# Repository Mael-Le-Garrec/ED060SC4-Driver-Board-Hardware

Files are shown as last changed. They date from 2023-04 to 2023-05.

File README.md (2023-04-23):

# ED060SC4 Driver Board

This projects intends to be a SPI driver board for the E-Ink display screen
`ED060SC4`.

This project is still under development, you can have a look at the schematics,
the PCB or the components, but it's not finished and will likely change!

## Schematics

The board is centered around 3 building blocks:

- ED060SC4, EPD screen
- STM32F103C8T6, microcontroller used to drive the screen
- TPS65185, used to generate the different rails required

The schematics can be found in [pdf](./outputs/schematics/ED060SC4_SPI_driver_board.pdf).

## Interactive Board

The PCB, nets and BOM can be seen in an [interactive html format](http://htmlpreview.github.io/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).

## Gerbers

The gerber files are available in a [zip archive](./outputs/gerbers/gerbers.zip)
ready to be sent for manufacturing.

## Images

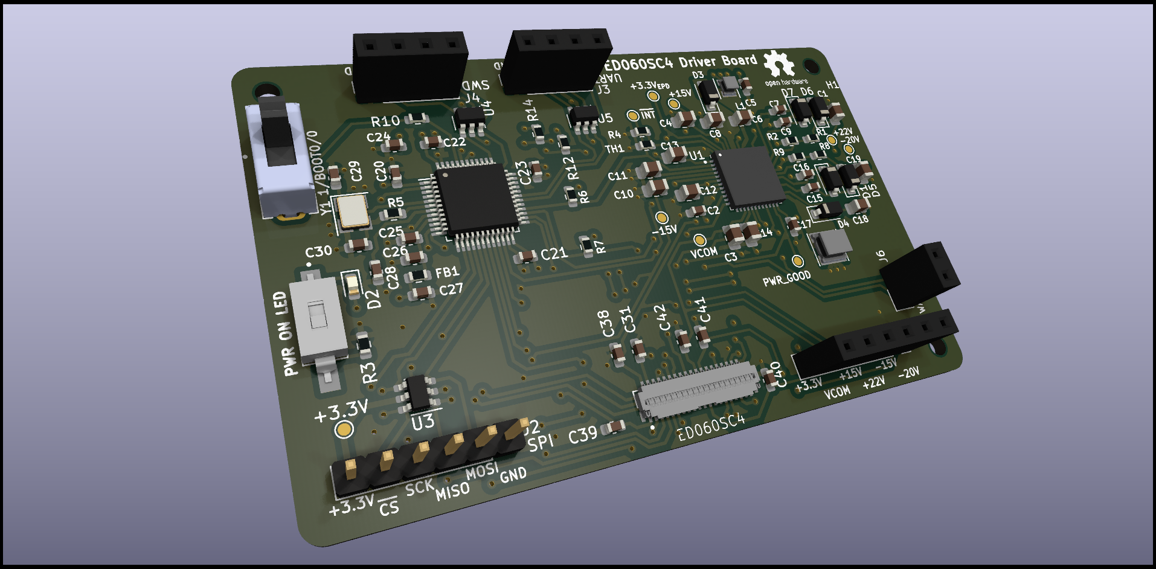
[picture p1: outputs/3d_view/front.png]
Front View

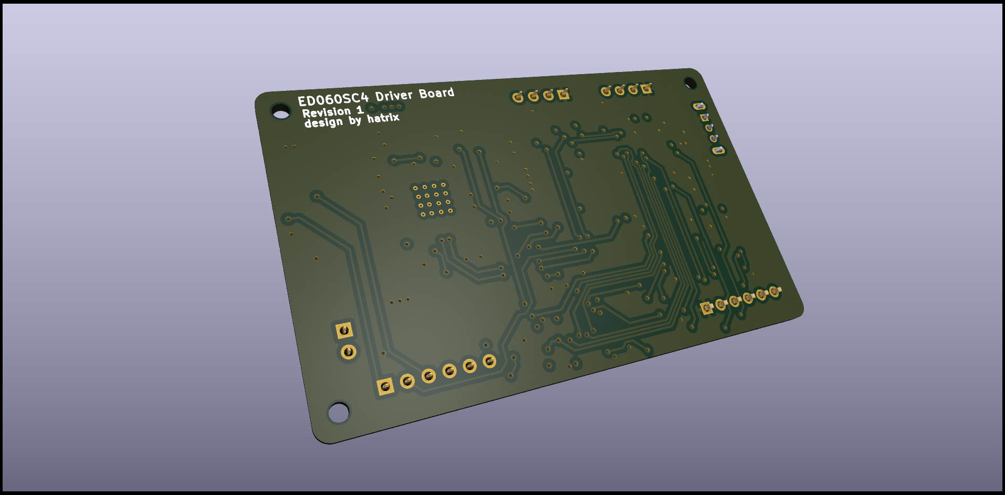
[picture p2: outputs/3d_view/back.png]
Back View

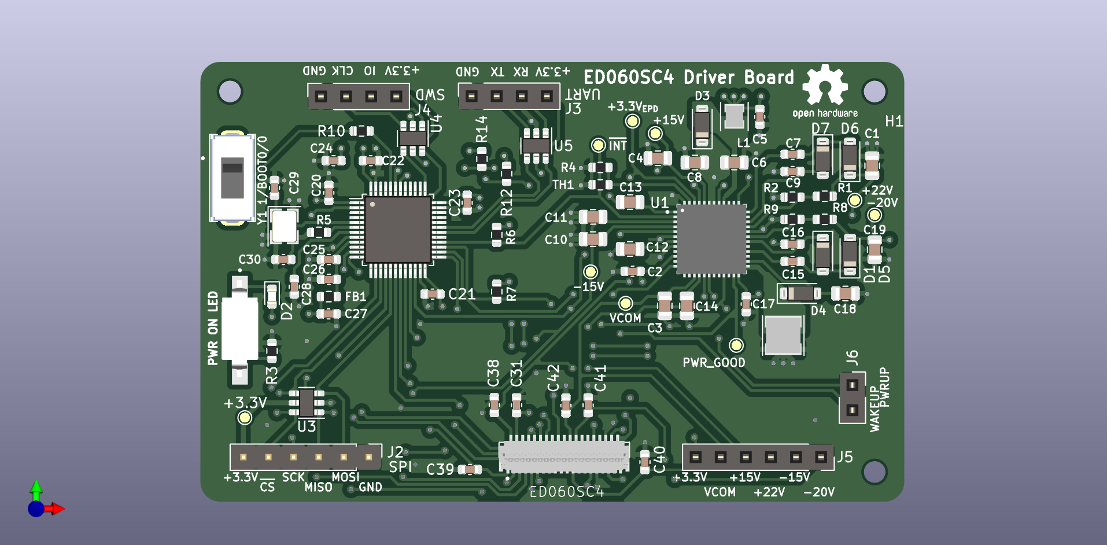
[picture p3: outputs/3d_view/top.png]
Top View

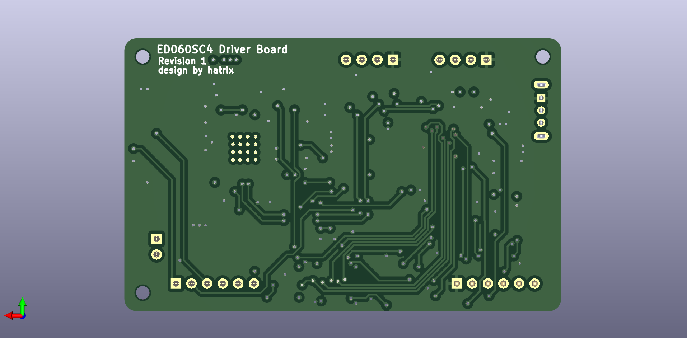
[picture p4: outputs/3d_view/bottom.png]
Bottom View


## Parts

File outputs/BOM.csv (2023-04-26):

Reference | Value | Footprint | LCSC Part # | Type | Voltage | Qty
C1, C4, C6, C8, C10, C11, C14, C18, C19 | 4.7µF | Capacitor_SMD:C_0805_2012Metric | C98192 | X6S | 50V | 9
C2, C17 | 10µF | Capacitor_SMD:C_0603_1608Metric | C85713 | X5R | 10V | 2
C3, C12, C13 | 4.7µF | Capacitor_SMD:C_0805_2012Metric | C98192 | X5R | 10V | 3
C5 | 10µF | Capacitor_SMD:C_0603_1608Metric | C85713 | X6S | 10V | 1
C7, C15 | 10nF | Capacitor_SMD:C_0603_1608Metric | C1589 | X7R | 25V | 2
C9, C16 | 100nF | Capacitor_SMD:C_0603_1608Metric | C1591 | X7R | 25V | 2
C20-C23, C28, C31, C42 | 100nF | Capacitor_SMD:C_0603_1608Metric | C1591 |  |  | 7
C24 | 10µF | Capacitor_SMD:C_0603_1608Metric | C85713 |  |  | 1
C25 | 10nF | Capacitor_SMD:C_0603_1608Metric | C1589 |  |  | 1
C26, C27 | 1µF | Capacitor_SMD:C_0603_1608Metric | C5673 |  |  | 2
C29, C30 | 10pF | Capacitor_SMD:C_0603_1608Metric | C1634 |  |  | 2
C38-C41 | 100nF | Capacitor_SMD:C_0603_1608Metric | C1591 |  | 50V | 4
D1, D5-D7 | D | Diode_SMD:D_SOD-123 | C82544 |  |  | 4
D2 | RED | LED_SMD:LED_0603_1608Metric | C82544 |  |  | 1
D3, D4 | D_Schottky | Diode_SMD:D_SOD-123 | C82544 |  |  | 2
FB1 | 120Ω@100MHz | Resistor_SMD:R_0603_1608Metric | C14709 |  |  | 1
H1, H2, H4 | M3 hole | MountingHole:MountingHole_2.2mm_M2 |  |  |  | 3
J1 | ED060SC4 | local_lib:HRS_FH26W-39S-0.3SHW(60) | C92280 |  |  | 1
J2 | Conn_01x06 | Connector_PinHeader_2.54mm:PinHeader_1x06_P2.54mm_Vertical |  |  |  | 1
J3, J4 | Conn_01x04 | Connector_PinSocket_2.54mm:PinSocket_1x04_P2.54mm_Vertical |  |  |  | 2
J5 | Conn_01x06 | Connector_PinSocket_2.54mm:PinSocket_1x06_P2.54mm_Vertical |  |  |  | 1
J6 | Conn_01x02 | Connector_PinSocket_2.54mm:PinSocket_1x02_P2.54mm_Vertical |  |  |  | 1
L1 | 2.2µH | local_lib:TDK_VLS252015ET-2R2M | C136232 |  |  | 1
L2 | 4.7µH | Inductor_SMD:L_Taiyo-Yuden_NR-40xx | C92936 |  |  | 1
R1, R8 | 1M | Resistor_SMD:R_0603_1608Metric | C105578 |  |  | 2
R2 | 47.5k | Resistor_SMD:R_0603_1608Metric | C137715 |  |  | 1
R3 | 1k | Resistor_SMD:R_0603_1608Metric | C22548 |  |  | 1
R4 | 43k | Resistor_SMD:R_0603_1608Metric | C137719 |  |  | 1
R5 | 0 | Resistor_SMD:R_0603_1608Metric | C103196 |  |  | 1
R6, R7, R10, R12, R14 | 10k | Resistor_SMD:R_0603_1608Metric | C98220 |  |  | 5
R9 | 52.3k | Resistor_SMD:R_0603_1608Metric | C185323 |  |  | 1
SW1 | SS12D07VG2 | local_lib:SW_SS12D07VG4 | C2939724 |  |  | 1
SW2 | DSIC01LSGET | local_lib:DSIC01LSGET | C54948 |  |  | 1
TH1 | 10k NTC | Resistor_SMD:R_0603_1608Metric | C13564 |  |  | 1
TP1-TP9 | TestPoint | TestPoint:TestPoint_Pad_D1.0mm |  |  |  | 9
U1 | TPS65185RGZR | local_lib:QFN50P700X700X100-49N | C139291 |  |  | 1
U2 | STM32F103C8T6 | Package_QFP:LQFP-48_7x7mm_P0.5mm | C8734 |  |  | 1
U3 | USBLC6-4SC6 | Package_TO_SOT_SMD:SOT-23-6 | C5197386 |  |  | 1
U4, U5 | USBLC6-2SC6 | Package_TO_SOT_SMD:SOT-23-6 | C2827654 |  |  | 2
Y1 | 16MHz, 10pF | Crystal:Crystal_SMD_3225-4Pin_3.2x2.5mm | C112972 |  |  | 1

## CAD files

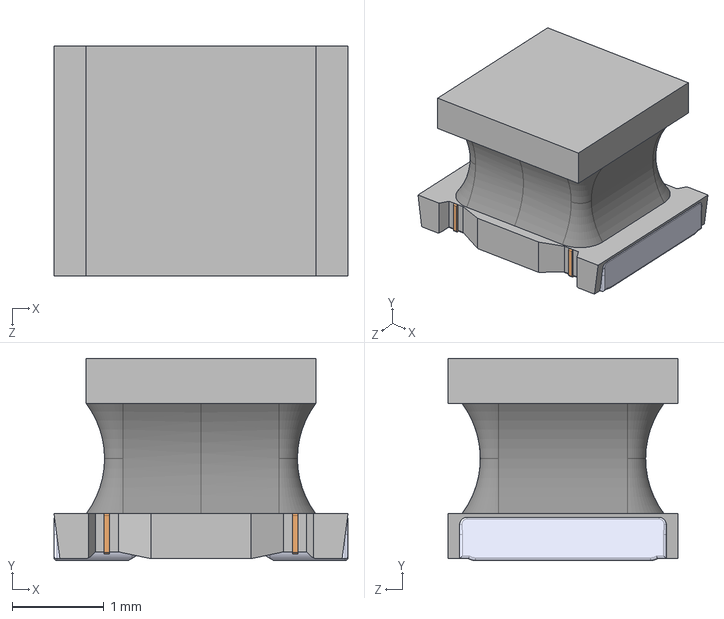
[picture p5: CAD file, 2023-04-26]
3d_models/generic_inductance.STEP
3.20 x 2.20 x 2.50 mm

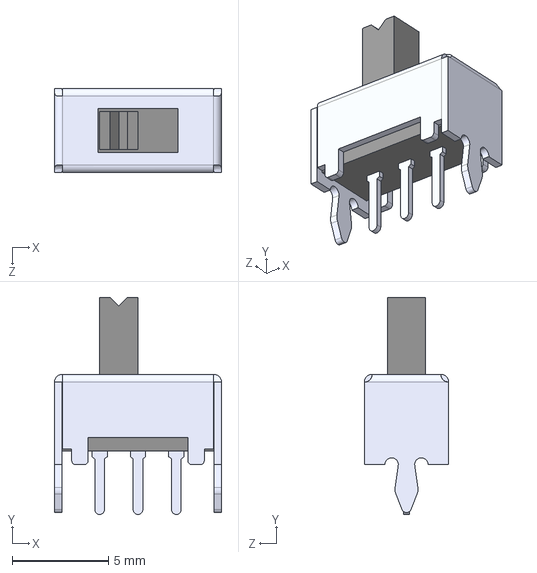
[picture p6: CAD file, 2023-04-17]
3d_models/SS12D07VG4.step
8.70 x 11.3 x 4.40 mm

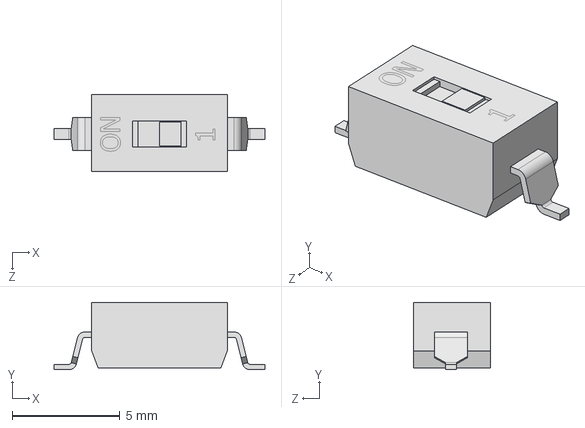
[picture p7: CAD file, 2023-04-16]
3d_models/KAE01SGGT.step
9.80 x 3.13 x 3.58 mm

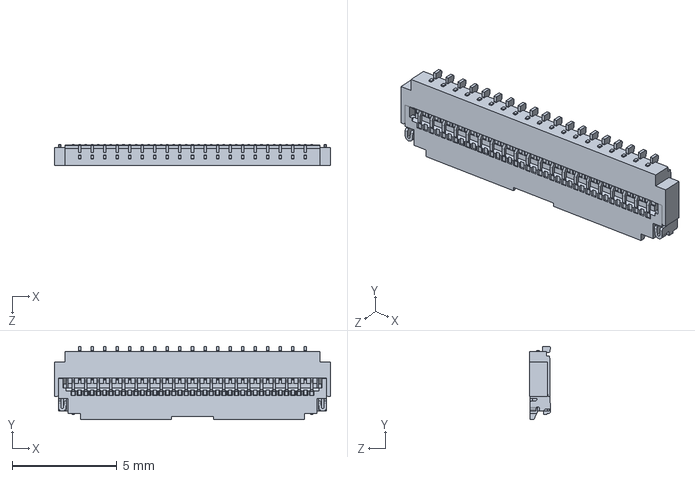
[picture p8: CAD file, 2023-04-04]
3d_models/WFH-2000118.STEP
13.2 x 3.50 x 1.00 mm

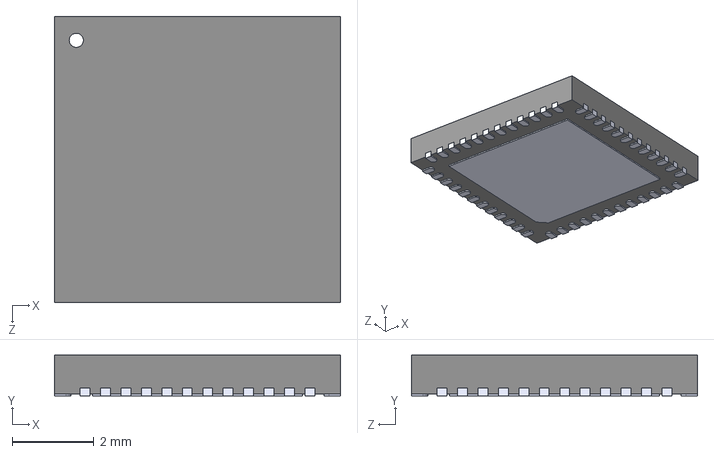
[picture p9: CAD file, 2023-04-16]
3d_models/TPS65185RGZR.step
7.00 x 1.00 x 7.00 mm

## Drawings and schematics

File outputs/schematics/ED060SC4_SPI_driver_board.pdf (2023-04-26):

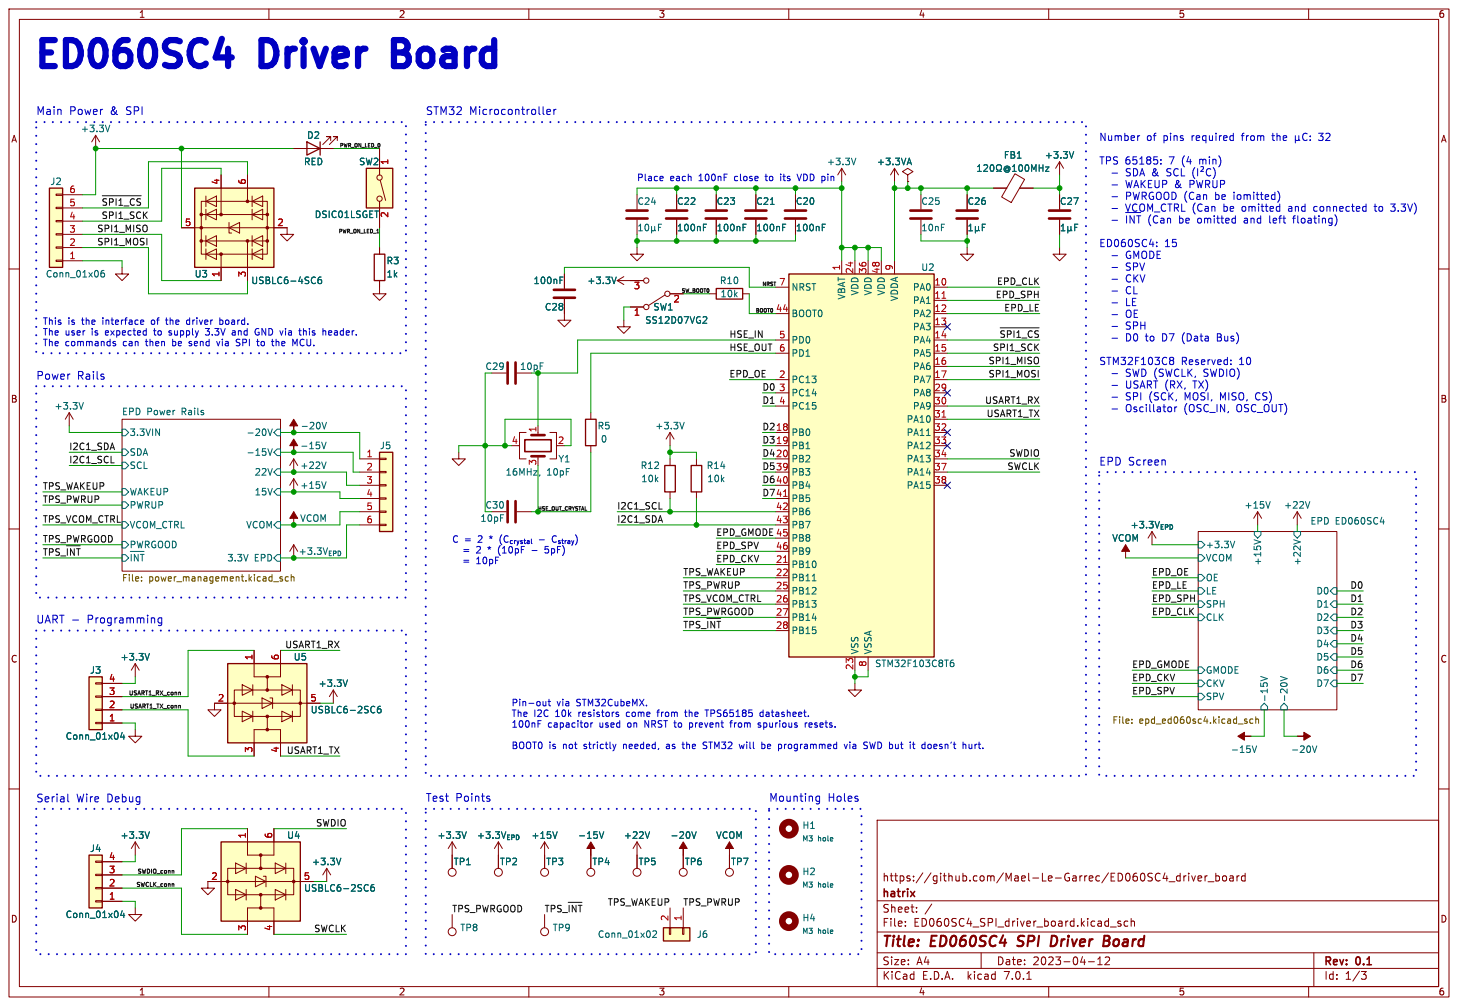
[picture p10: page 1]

- SDA & SCL þÿ(I²C)
- WAKEUP & PWRUP
- PWRGOOD (Can be iomitted)
- ~{INT}(Can be omitted and left floating) ED060SC4: 15

1 PA0 10 PA1 11 PA2 12 PA3 13 PA4 14 PA5 15 PA6 16 PA7 17 PB0 18 PB1 19 PC13 2 PB2 20 PB10 21 PB11 22 VSS 23 VDD 24 PB12 25 PB13 26 PB14 27 PB15 28 PA8 29 PC14 3 PA9 30 PA10 31 PA11 32 PA12 33 PA13 34 VDD 36 PA14 37 PA15 38 PB3 39 PC15 4 PB4 40 PB5 41 PB6 42 PB7 43 BOOT0 44 PB8 45 PB9 46 VDD 48 PD0 5 PD1 6 NRST 7 VSSA

- SWD (SWCLK, SWDIO)
- USART (RX, TX)
- SPI (SCK, MOSI, MISO, CS)

https://github.com/Mael-Le-Garrec/ED060SC4_driver_board

Id: 1/3 Title: ED060SC4 SPI Driver Board

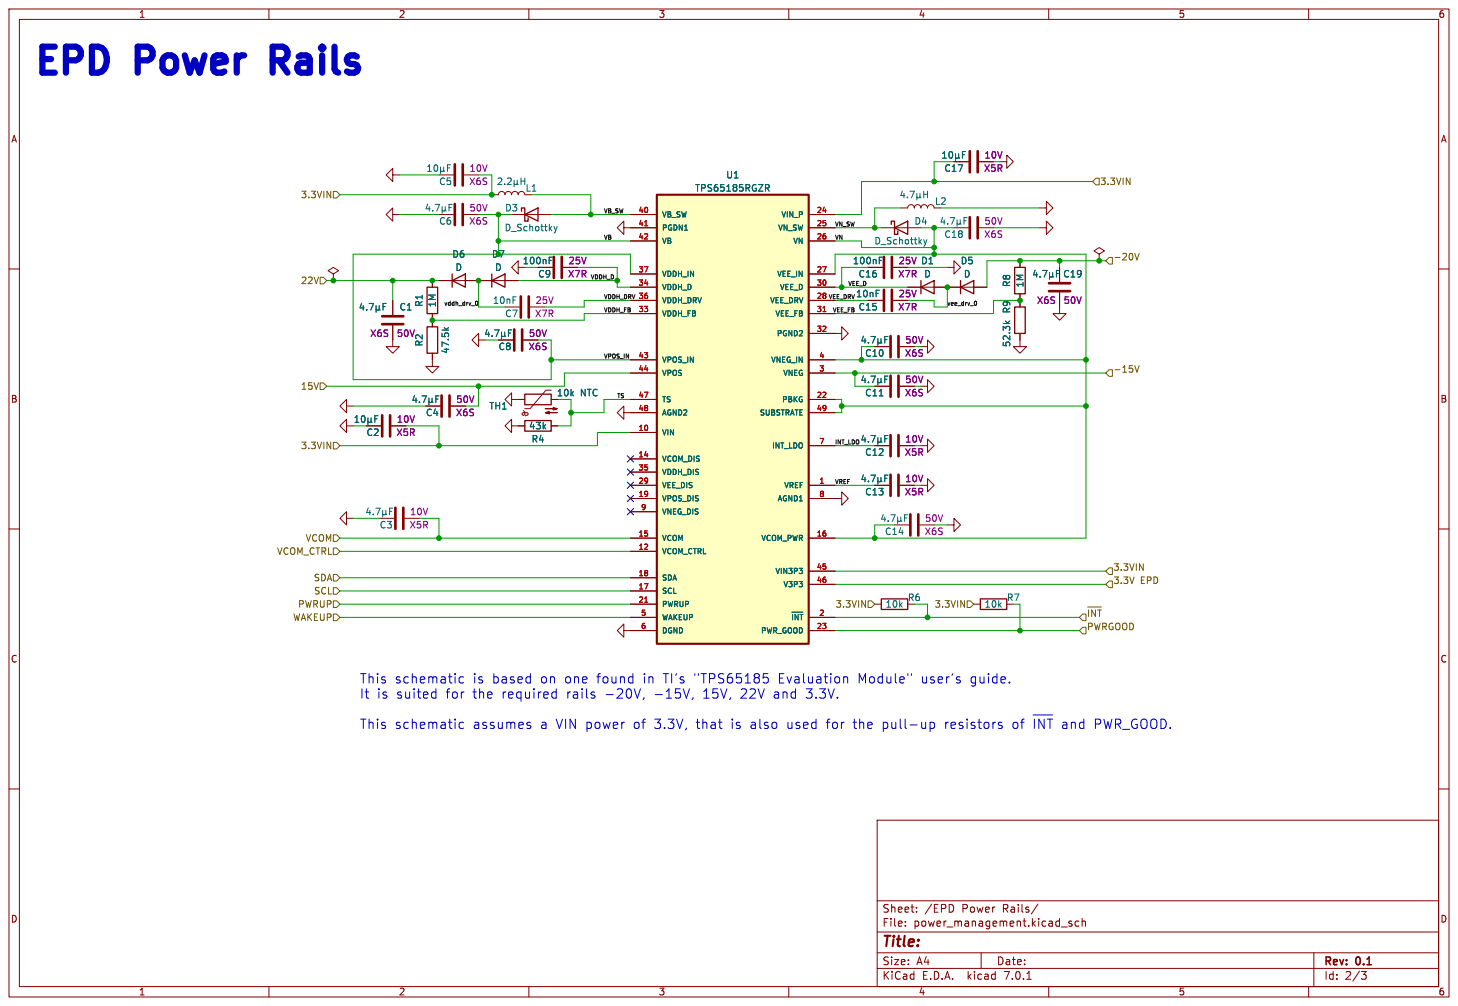
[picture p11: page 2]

It is suited for the required rails -20V, -15V, 15V, 22V and 3.3V.

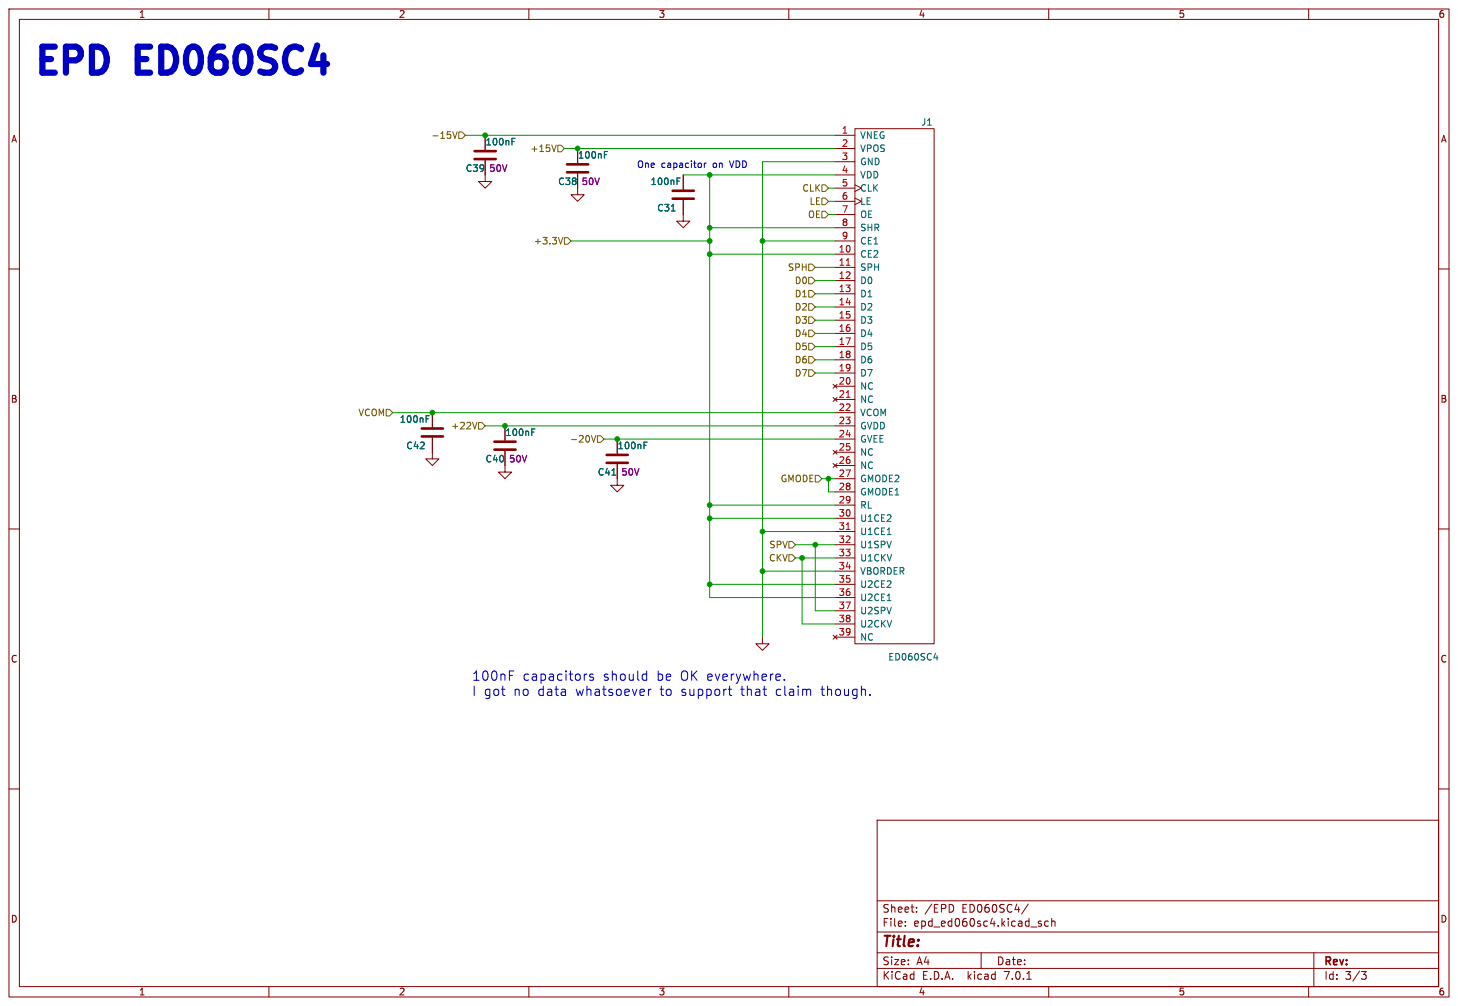
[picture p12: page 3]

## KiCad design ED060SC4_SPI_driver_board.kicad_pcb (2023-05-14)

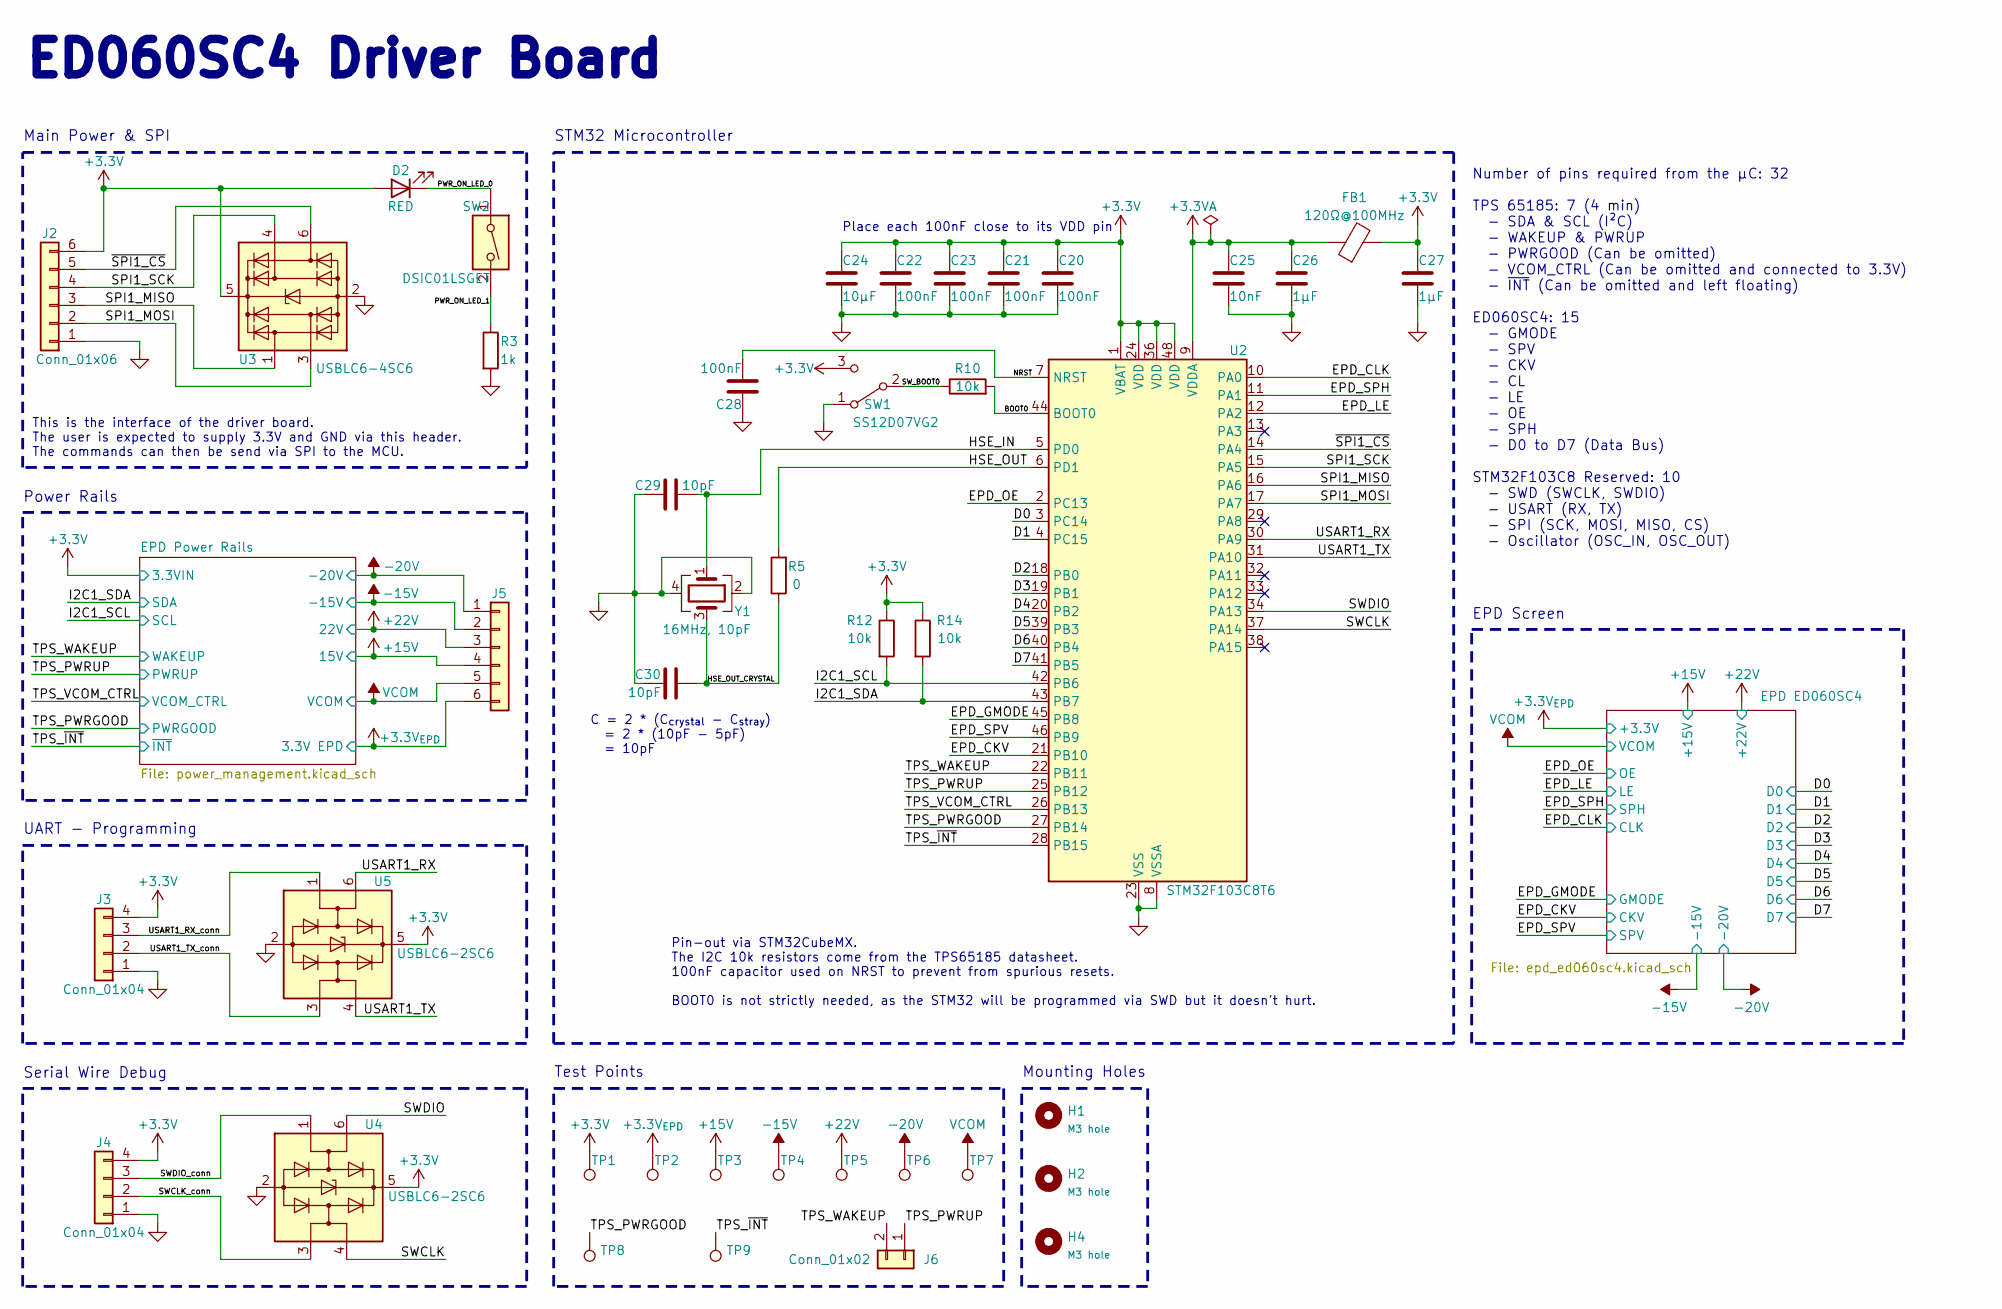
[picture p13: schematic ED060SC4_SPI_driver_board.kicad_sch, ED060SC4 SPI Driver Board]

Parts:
C20, C21, C22, C23, C28: 100nF; C_0603_1608Metric; LCSC Part # C1591
C24: 10µF; C_0603_1608Metric; LCSC Part # C85713
C25: 10nF; C_0603_1608Metric; LCSC Part # C1589
C26, C27: 1µF; C_0603_1608Metric; LCSC Part # C5673
C29, C30: 10pF; C_0603_1608Metric; LCSC Part # C1634
D2: RED; LED_0603_1608Metric; LCSC Part # C434419
FB1: 120Ω@100MHz; R_0603_1608Metric; LCSC Part # C14709
H1, H2, H4: M3 hole; MountingHole_2.2mm_M2
J2: Conn_01x06; PinHeader_1x06_P2.54mm_Vertical
J3, J4: Conn_01x04; PinSocket_1x04_P2.54mm_Vertical
J5: Conn_01x06; PinSocket_1x06_P2.54mm_Vertical
J6: Conn_01x02; PinSocket_1x02_P2.54mm_Vertical
R3: 1k; R_0603_1608Metric; LCSC Part # C22548
R5: 0; R_0603_1608Metric; LCSC Part # C103196
R10, R12, R14: 10k; R_0603_1608Metric; LCSC Part # C98220
SW1: SS12D07VG2; SW_SS12D07VG4; LCSC Part # C2939724
SW2: DSIC01LSGET; LCSC Part # C54948
TP1, TP2, TP3, TP4, TP5, TP6, TP7, TP8, TP9: TestPoint; TestPoint_Pad_D1.0mm
U2: STM32F103C8T6; LQFP-48_7x7mm_P0.5mm; LCSC Part # C8734
U3: USBLC6-4SC6; SOT-23-6; LCSC Part # C5197386
U4, U5: USBLC6-2SC6; SOT-23-6; LCSC Part # C2827654
Y1: 16MHz, 10pF; Crystal_SMD_3225-4Pin_3.2x2.5mm; LCSC Part # C112972

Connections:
+3.3V: C20.1, C21.1, C22.1, C23.1, C24.1, C27.1, D2.2 (A), FB1.2, J2.6, J3.4, J4.4, R12.1, R14.1, SW1.3 (C), TP1.1, U2.1 (VBAT), U2.24 (VDD), U2.36 (VDD), U2.48 (VDD), U3.5 (VBUS), U4.5 (VBUS), U5.5 (VBUS); also elsewhere on the board
+3.3VA: C25.1, C26.1, FB1.1, U2.9 (VDDA)
+15V: J5.4, TP3.1; also elsewhere on the board
+22V: J5.3, TP5.1; also elsewhere on the board
-15V: J5.2, TP4.1; also elsewhere on the board
-20V: J5.1, TP6.1; also elsewhere on the board
/BOOT0: R10.2, U2.44 (BOOT0)
/D0: U2.3 (PC14); also elsewhere on the board
/D1: U2.4 (PC15); also elsewhere on the board
/D2: U2.18 (PB0); also elsewhere on the board
/D3: U2.19 (PB1); also elsewhere on the board
/D4: U2.20 (PB2); also elsewhere on the board
/D5: U2.39 (PB3); also elsewhere on the board
/D6: U2.40 (PB4); also elsewhere on the board
/D7: U2.41 (PB5); also elsewhere on the board
/EPD_CKV: U2.21 (PB10); also elsewhere on the board
/EPD_CLK: U2.10 (PA0); also elsewhere on the board
/EPD_GMODE: U2.45 (PB8); also elsewhere on the board
/EPD_LE: U2.12 (PA2); also elsewhere on the board
/EPD_OE: U2.2 (PC13); also elsewhere on the board
/EPD_SPH: U2.11 (PA1); also elsewhere on the board
/EPD_SPV: U2.46 (PB9); also elsewhere on the board
/HSE_IN: C29.2, U2.5 (PD0), Y1.1
/HSE_OUT: R5.2, U2.6 (PD1)
/HSE_OUT_CRYSTAL: C30.2, R5.1, Y1.3
/I2C1_SCL: R12.2, U2.42 (PB6); also elsewhere on the board
/I2C1_SDA: R14.2, U2.43 (PB7); also elsewhere on the board
/NRST: C28.2, U2.7 (NRST)
/PWR_ON_LED_0: D2.1 (K), SW2.1
/PWR_ON_LED_1: R3.1, SW2.2
/SPI1_MISO: J2.3, U2.16 (PA6), U3.1 (I/O1)
/SPI1_MOSI: J2.2, U2.17 (PA7), U3.3 (I/O2)
/SPI1_SCK: J2.4, U2.15 (PA5), U3.4 (I/O3)
/SWCLK: U2.37 (PA14), U4.4 (I/O2)
/SWCLK_conn: J4.2, U4.3 (I/O2)
/SWDIO: U2.34 (PA13), U4.6 (I/O1)
/SWDIO_conn: J4.3, U4.1 (I/O1)
/SW_BOOT0: R10.1, SW1.2 (B)
/TPS_PWRGOOD: TP8.1, U2.27 (PB14); also elsewhere on the board
/TPS_PWRUP: J6.1, U2.25 (PB12); also elsewhere on the board
/TPS_VCOM_CTRL: U2.26 (PB13); also elsewhere on the board
/TPS_WAKEUP: J6.2, U2.22 (PB11); also elsewhere on the board
/TPS_~INT: TP9.1, U2.28 (PB15); also elsewhere on the board
/USART1_RX: U2.30 (PA9), U5.6 (I/O1)
/USART1_RX_conn: J3.3, U5.1 (I/O1)
/USART1_TX: U2.31 (PA10), U5.4 (I/O2)
/USART1_TX_conn: J3.2, U5.3 (I/O2)
/~SPI1_CS: J2.5, U2.14 (PA4), U3.6 (I/O4)
GND: C20.2, C21.2, C22.2, C23.2, C24.2, C25.2, C26.2, C27.2, C28.1, C29.1, C30.1, J2.1, J3.1, J4.1, R3.2, SW1.1 (A), U2.8 (VSSA), U2.23 (VSS), U2.35 (VSS), U2.47 (VSS), U3.2 (GND), U4.2 (GND), U5.2 (GND), Y1.2, Y1.4; also elsewhere on the board

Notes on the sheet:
Number of pins required from the µC: 32 TPS 65185: 7 (4 min) - SDA & SCL (I²C) - WAKEUP & PWRUP - PWRGOOD (Can be omitted) - VCOM_CTRL (Can be omitted and connected to 3.3V) - ~{INT} (Can be omitted and left floating) ED060SC4: 15 - GMODE - SPV - CKV - CL - LE - OE - SPH - D0 to D7 (Data Bus) STM32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
Pin-out via STM32CubeMX. The I2C 10k resistors come from the TPS65185 datasheet. 100nF capacitor used on NRST to prevent from spurious resets. BOOT0 is not strictly needed, as the STM32 will be programmed via SWD but it doesn't hurt.
EPD Screen
STM32 Microcontroller
Main Power & SPI
Power Rails
This is the interface of the driver board. The user is expected to supply 3.3V and GND via this header. The commands can then be send via SPI to the MCU.
Place each 100nF close to its VDD pin
ED060SC4 Driver Board
Serial Wire Debug
Test Points
C = 2 * (C_{crystal} - C_{stray}) = 2 * (10pF - 5pF) = 10pF
UART - Programming
Mounting Holes

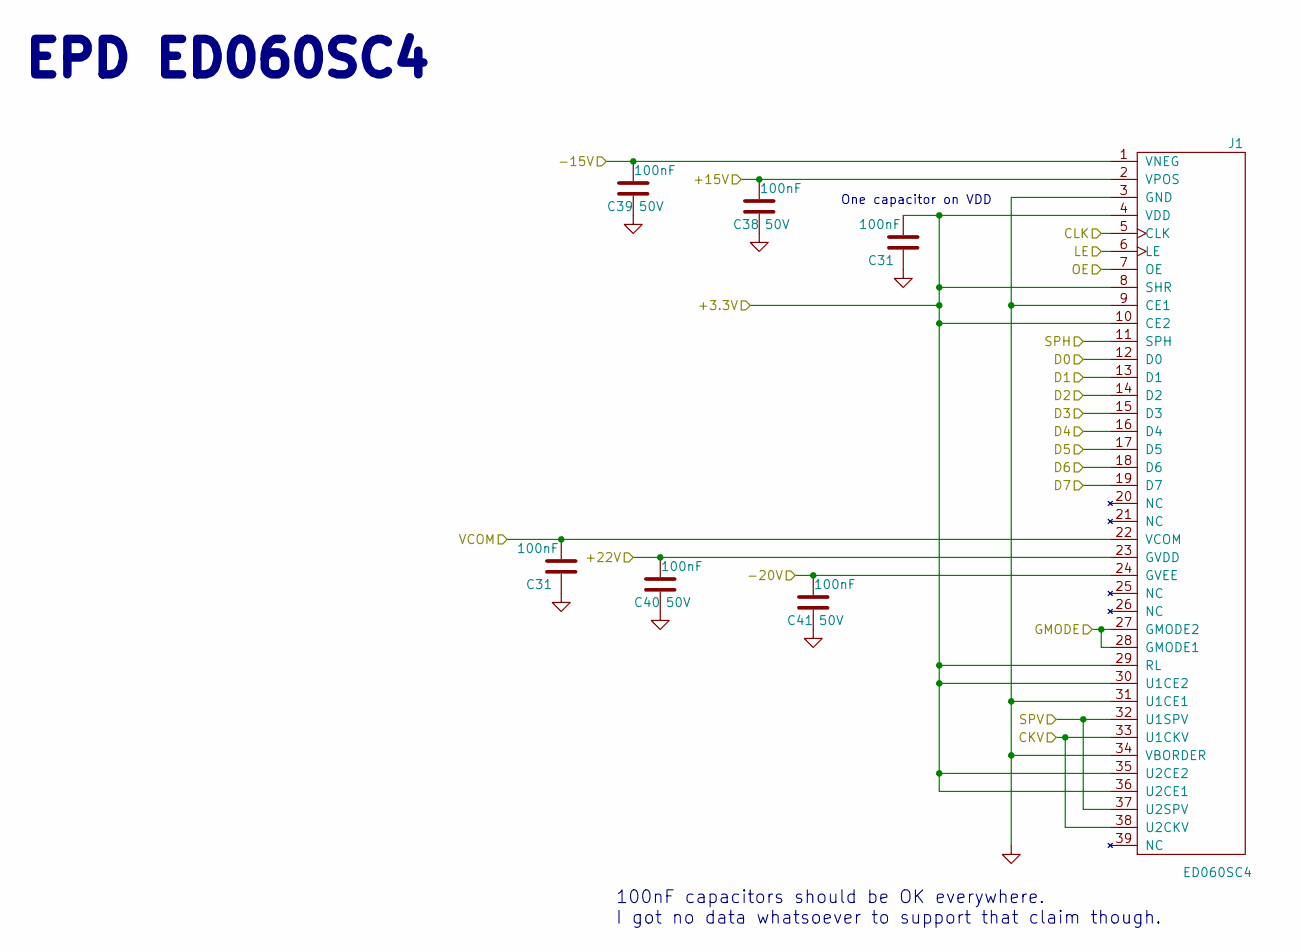
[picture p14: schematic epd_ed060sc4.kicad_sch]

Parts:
C31: 100nF; C_0603_1608Metric; LCSC Part # C1591
C38, C39, C40, C41: 100nF; C_0603_1608Metric; Voltage 50V; LCSC Part # C1591
J1: ED060SC4; HRS_FH26W-39S-0.3SHW(60); LCSC Part # C92280

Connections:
+15V: C38.1, J1.2 (VPOS); also elsewhere on the board
+22V: C40.1, J1.23 (GVDD); also elsewhere on the board
-15V: C39.1, J1.1 (VNEG); also elsewhere on the board
-20V: C41.1, J1.24 (GVEE); also elsewhere on the board
/D0: J1.12 (D0); also elsewhere on the board
/D1: J1.13 (D1); also elsewhere on the board
/D2: J1.14 (D2); also elsewhere on the board
/D3: J1.15 (D3); also elsewhere on the board
/D4: J1.16 (D4); also elsewhere on the board
/D5: J1.17 (D5); also elsewhere on the board
/D6: J1.18 (D6); also elsewhere on the board
/D7: J1.19 (D7); also elsewhere on the board
/EPD_CKV: J1.33 (U1CKV), J1.38 (U2CKV); also elsewhere on the board
/EPD_CLK: J1.5 (CLK); also elsewhere on the board
/EPD_GMODE: J1.27 (GMODE2), J1.28 (GMODE1); also elsewhere on the board
/EPD_LE: J1.6 (LE); also elsewhere on the board
/EPD_OE: J1.7 (OE); also elsewhere on the board
/EPD_SPH: J1.11 (SPH); also elsewhere on the board
/EPD_SPV: J1.32 (U1SPV), J1.37 (U2SPV); also elsewhere on the board
GND: C31.2, C38.2, C39.2, C40.2, C41.2, J1.3 (GND), J1.9 (CE1), J1.31 (U1CE1), J1.34 (VBORDER); also elsewhere on the board

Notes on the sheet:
100nF capacitors should be OK everywhere. I got no data whatsoever to support that claim though.
One capacitor on VDD
EPD ED060SC4

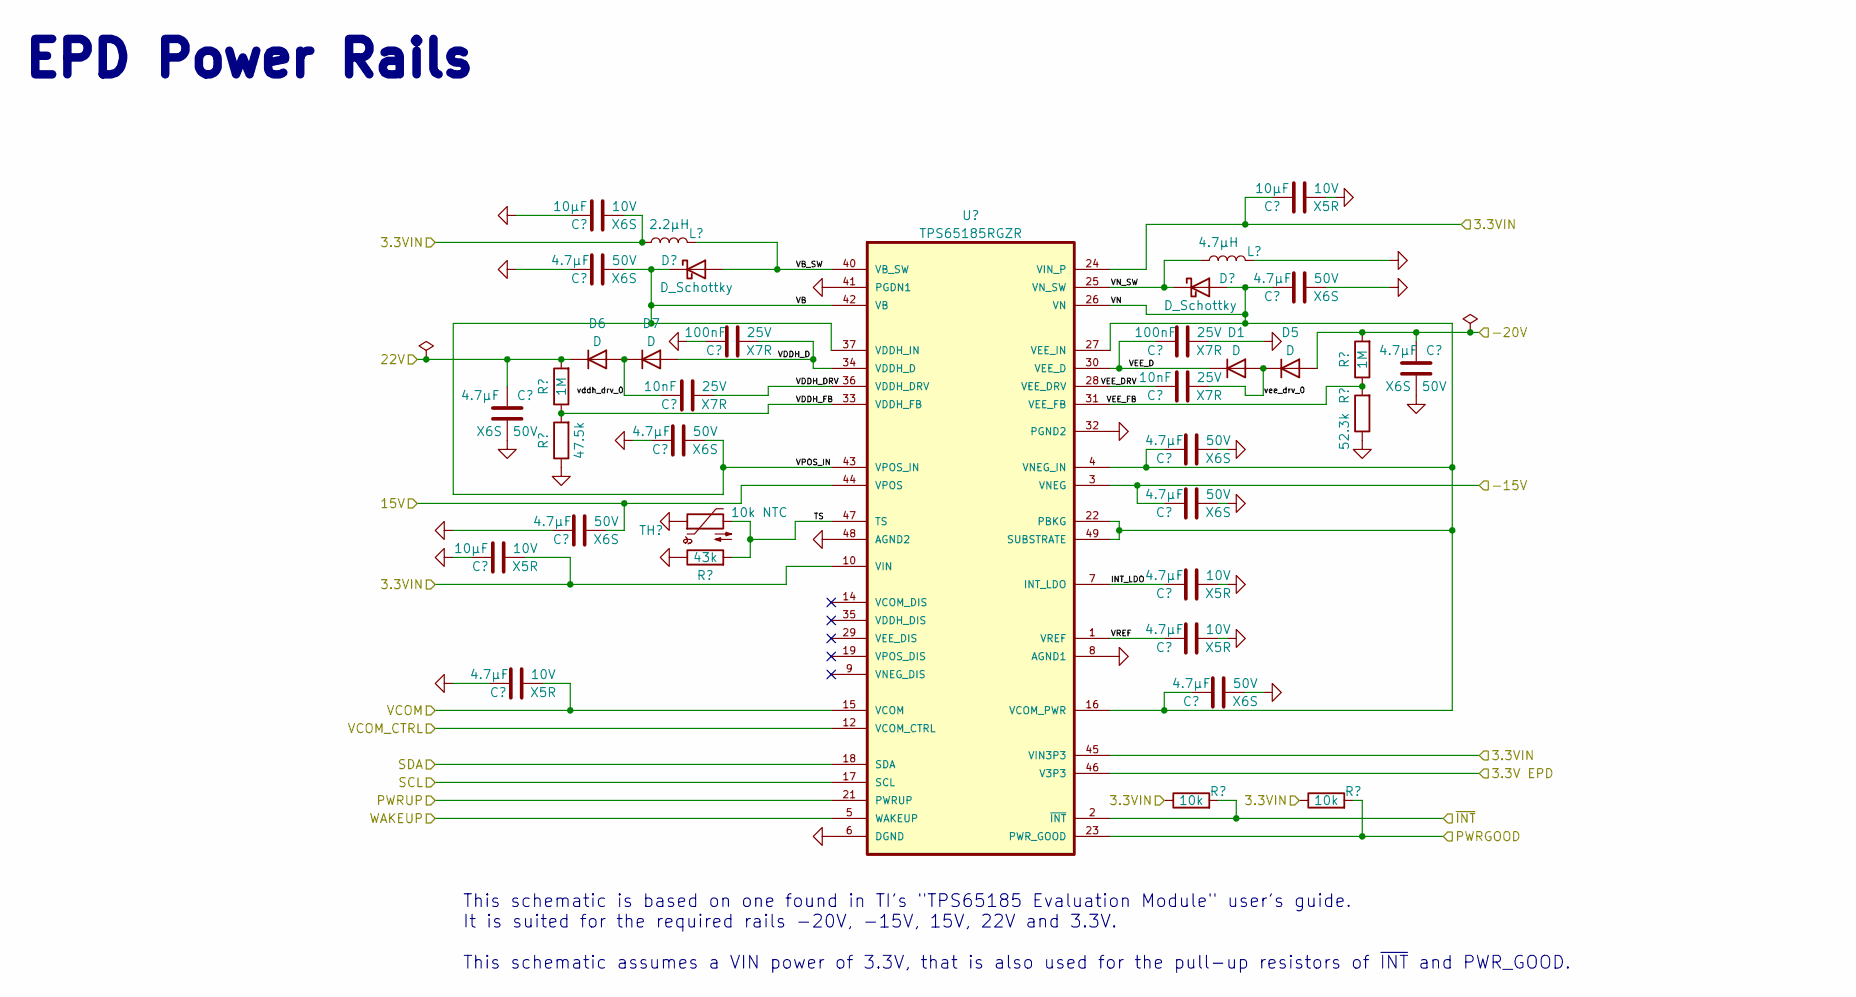
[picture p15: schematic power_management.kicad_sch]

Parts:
C1, C4, C6, C8, C10, C11, C14, C18, C19: 4.7µF; C_0805_2012Metric; Voltage 50V; LCSC Part # C98192
C2, C5, C17: 10µF; C_0603_1608Metric; Voltage 10V; LCSC Part # C85713
C3, C12, C13: 4.7µF; C_0805_2012Metric; Voltage 10V; LCSC Part # C98192
C7, C15: 10nF; C_0603_1608Metric; Voltage 25V; LCSC Part # C1589
C9, C16: 100nF; C_0603_1608Metric; Voltage 25V; LCSC Part # C1591
D1, D5, D6, D7: D; D_SOD-123; LCSC Part # C82544
D3, D4: D_Schottky; D_SOD-123; LCSC Part # C82544
L1: 2.2µH; TDK_VLS252015ET-2R2M; LCSC Part # C136232
L2: 4.7µH; L_Taiyo-Yuden_NR-40xx; LCSC Part # C92936
R1, R8: 1M; R_0603_1608Metric; LCSC Part # C105578
R2: 47.5k; R_0603_1608Metric; LCSC Part # C137715
R4: 43k; R_0603_1608Metric; LCSC Part # C137719
R6, R7: 10k; R_0603_1608Metric; LCSC Part # C98220
R9: 52.3k; R_0603_1608Metric; LCSC Part # C185323
TH1: 10k NTC; R_0603_1608Metric; LCSC Part # C13564
U1: TPS65185RGZR; QFN50P700X700X100-49N; LCSC Part # C139291

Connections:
+3.3V: C2.1, C5.2, C17.2, L1.1, R6.1, R7.1, U1.10 (VIN), U1.24 (VIN_P), U1.45 (VIN3P3); also elsewhere on the board
+15V: C4.1, U1.44 (VPOS); also elsewhere on the board
+22V: C1.2, D6.1 (K), R1.2; also elsewhere on the board
-15V: C11.1, U1.3 (VNEG); also elsewhere on the board
-20V: C19.2, D5.2 (A), R8.2; also elsewhere on the board
/EPD Power Rails/INT_LDO: C12.1, U1.7 (INT_LDO)
/EPD Power Rails/TS: R4.2, TH1.2, U1.47 (TS)
/EPD Power Rails/VB: C6.2, C8.2, D3.1 (K), U1.37 (VDDH_IN), U1.42 (VB), U1.43 (VPOS_IN)
/EPD Power Rails/VB_SW: D3.2 (A), L1.2, U1.40 (VB_SW)
/EPD Power Rails/VDDH_D: C9.2, D7.2 (A), U1.34 (VDDH_D)
/EPD Power Rails/VDDH_DRV: C7.2, U1.36 (VDDH_DRV)
/EPD Power Rails/VDDH_FB: R1.1, R2.2, U1.33 (VDDH_FB)
/EPD Power Rails/VEE_D: C16.2, D1.1 (K), U1.30 (VEE_D)
/EPD Power Rails/VEE_DRV: C15.1, U1.28 (VEE_DRV)
/EPD Power Rails/VEE_FB: R8.1, R9.2, U1.31 (VEE_FB)
/EPD Power Rails/VN: C10.1, C14.1, C18.2, D4.2 (A), U1.4 (VNEG_IN), U1.16 (VCOM_PWR), U1.22 (PBKG), U1.26 (VN), U1.27 (VEE_IN), U1.49 (SUBSTRATE)
/EPD Power Rails/VN_SW: D4.1 (K), L2.2, U1.25 (VN_SW)
/EPD Power Rails/VREF: C13.1, U1.1 (VREF)
/EPD Power Rails/vddh_drv_0: C7.1, D6.2 (A), D7.1 (K)
/EPD Power Rails/vee_drv_0: C15.2, D1.2 (A), D5.1 (K)
/I2C1_SCL: U1.17 (SCL); also elsewhere on the board
/I2C1_SDA: U1.18 (SDA); also elsewhere on the board
/TPS_PWRGOOD: R7.2, U1.23 (PWR_GOOD); also elsewhere on the board
/TPS_PWRUP: U1.21 (PWRUP); also elsewhere on the board
/TPS_VCOM_CTRL: U1.12 (VCOM_CTRL); also elsewhere on the board
/TPS_WAKEUP: U1.5 (WAKEUP); also elsewhere on the board
/TPS_~INT: R6.2, U1.2 (~INT); also elsewhere on the board
GND: C1.1, C2.2, C3.2, C4.2, C5.1, C6.1, C8.1, C9.1, C10.2, C11.2, C12.2, C13.2, C14.2, C16.1, C17.1, C18.1, C19.1, L2.1, R2.1, R4.1, R9.1, TH1.1, U1.6 (DGND), U1.8 (AGND1), U1.32 (PGND2), U1.41 (PGDN1), U1.48 (AGND2); also elsewhere on the board

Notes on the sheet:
This schematic is based on one found in TI's "TPS65185 Evaluation Module" user's guide. It is suited for the required rails -20V, -15V, 15V, 22V and 3.3V. This schematic assumes a VIN power of 3.3V, that is also used for the pull-up resistors of ~{INT} and PWR_GOOD.
EPD Power Rails

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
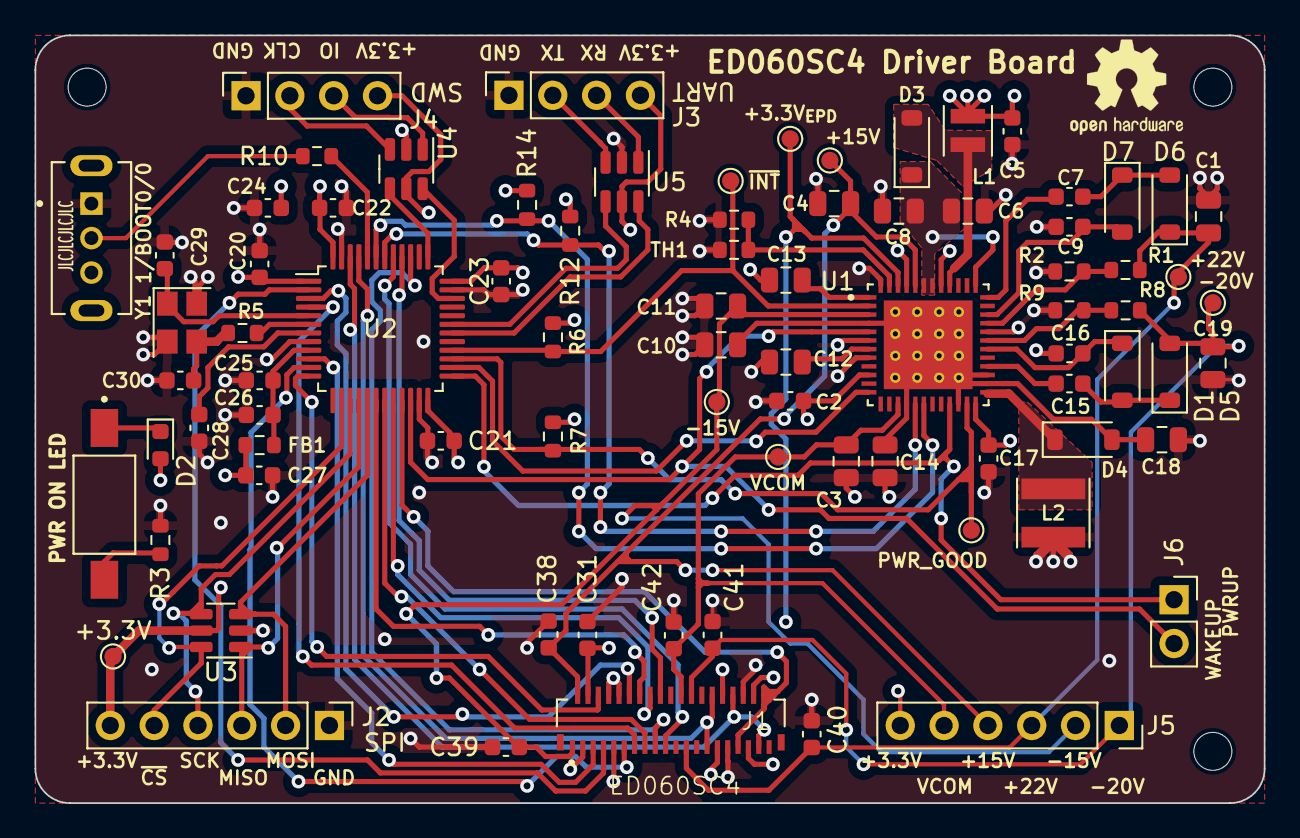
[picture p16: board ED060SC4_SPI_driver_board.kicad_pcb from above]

Board: 4 copper layers, 71.2 x 44.5 mm, 85 parts (0 on the bottom side), 66 nets.

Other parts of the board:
C42: 100nF; C_0603_1608Metric

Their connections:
GND: C42.2; also elsewhere on the board

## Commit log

2023-04-04 Starting to wire the TPS65185 PMIC
    [ED060SC4_SPI_driver_board.kicad_pcb, ED060SC4_SPI_driver_board.kicad_sch, WFH-2000118.STEP]
2023-04-10 Wired TPS65185 according to datasheet
    [ED060SC4_SPI_driver_board.kicad_sch, power_management.kicad_sch]
2023-04-13 Full Schematic
    [ED060SC4_SPI_driver_board.kicad_sch, epd_ed060sc4.kicad_sch, power_management.kicad_sch]
2023-04-13 Rearrange schematic
    [ED060SC4_SPI_driver_board.kicad_sch, power_management.kicad_sch]
2023-04-13 add pdf schematic
2023-04-16 fix paths
    [epd_ed060sc4.kicad_sch, power_management.kicad_sch]
2023-04-16 Use DIP switch for power LED
    [ED060SC4_SPI_driver_board.kicad_sch]
2023-04-16 Update library path and add DIP switch
    [ED060SC4_SPI_driver_board.kicad_sch, KAE01SGGT.step, TPS65185RGZR.step]
2023-04-16 set value of dip led switch
    [ED060SC4_SPI_driver_board.kicad_sch]
2023-04-16 Set voltage rating of capacitors
    [epd_ed060sc4.kicad_sch, power_management.kicad_sch]
2023-04-16 Add footprints and some labels
    [ED060SC4_SPI_driver_board.kicad_sch, epd_ed060sc4.kicad_sch, power_management.kicad_sch]
2023-04-17 Update TPS65185 based on evaluation module
    [power_management.kicad_sch]
2023-04-17 Add ESD and SPDT switch
    [ED060SC4_SPI_driver_board.kicad_sch, SS12D07VG4.step]
2023-04-17 Update EPD capacitors
    [epd_ed060sc4.kicad_sch, power_management.kicad_sch]
2023-04-17 Changed VDDH and VEE capacitors to 4.7µF
    The evaluation board uses 4.7µF capacitors instead of 2.2µF as stated in
    the datasheet.
    [power_management.kicad_sch]
2023-04-19 Fixed PWR flags in schematic
    [ED060SC4_SPI_driver_board.kicad_sch, epd_ed060sc4.kicad_sch, power_management.kicad_sch]
2023-04-19 First rough PCB layout without traces
    [ED060SC4_SPI_driver_board.kicad_pcb]
2023-04-19 Add a connector for easy access to voltages
    [ED060SC4_SPI_driver_board.kicad_pcb, ED060SC4_SPI_driver_board.kicad_sch]
2023-04-20 PCB routing
    [ED060SC4_SPI_driver_board.kicad_pcb, ED060SC4_SPI_driver_board.kicad_sch]
2023-04-23 TPS Connector and LCSC part #
    [ED060SC4_SPI_driver_board.kicad_sch]
2023-04-23 Change D footprint for TPS and LCSC part #
    [power_management.kicad_sch]
2023-04-23 Remove some capacitors for EPD
    [epd_ed060sc4.kicad_sch]
2023-04-23 Routed PCB + outputs
    [BOM.csv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]
2023-04-23 Updated TPS pad for heat dissipation
    [ED060SC4_SPI_driver_board-B_Cu.gbl, ED060SC4_SPI_driver_board-B_Mask.gbs, ED060SC4_SPI_driver_board-B_Paste.gbp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]
2023-04-23 Smaller board outline and some silkscreen info
    [ED060SC4_SPI_driver_board-B_Cu.gbl, ED060SC4_SPI_driver_board-B_Cu.gbr, ED060SC4_SPI_driver_board-B_Mask.gbr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]
2023-04-23 bigger via holes for TPS heat
    [ED060SC4_SPI_driver_board.kicad_pcb]
2023-04-23 Update outputs
    [ED060SC4_SPI_driver_board-B_Cu.gbl, ED060SC4_SPI_driver_board-B_Mask.gbs, ED060SC4_SPI_driver_board-B_Paste.gbp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]
2023-04-24 Add ground pour to external layers
    [ED060SC4_SPI_driver_board.kicad_pcb]
2023-04-24 Add titles to schematics
    [ED060SC4_SPI_driver_board.kicad_sch, epd_ed060sc4.kicad_sch, power_management.kicad_sch]
2023-04-25 Add mounting holes
    [ED060SC4_SPI_driver_board.kicad_pcb, ED060SC4_SPI_driver_board.kicad_sch]
2023-04-26 add generic 3D model for L1 and L2
    [ED060SC4_SPI_driver_board.kicad_pcb, generic_inductance.STEP]
2023-04-26 Add mounting holes and connector to Bom (empty)
    [BOM.csv]
2023-04-26 Fix LED BOM # and update outputs
    [ED060SC4_SPI_driver_board-B_Cu.gbl, ED060SC4_SPI_driver_board-B_Mask.gbs, ED060SC4_SPI_driver_board-B_Paste.gbp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]
2023-04-26 fix LED in iBOM
2023-04-26 add JLC order # text for location
    [ED060SC4_SPI_driver_board-B_Cu.gbl, ED060SC4_SPI_driver_board-B_Mask.gbs, ED060SC4_SPI_driver_board-B_Paste.gbp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]
2023-04-29 add svg schematics
2023-04-29 Add VN pad under TPS and fix some typos
    [ED060SC4_SPI_driver_board.kicad_pcb, ED060SC4_SPI_driver_board.kicad_sch]
2023-05-14 Fix unaligned hole
    [ED060SC4_SPI_driver_board.kicad_pcb]
